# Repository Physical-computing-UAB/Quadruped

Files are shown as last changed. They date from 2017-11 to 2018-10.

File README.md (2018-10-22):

# Quadruped

Robot cuadrúpedo hecho con arduino y rasperry pi. Entre los dispositivos utilizados se encuentran:
- Motores Servo y paso a paso
- Sensores Ultrasonido HC-SRO4
- Camara raspberry NoIR
-
-

(Vídeos e imágenes: https://drive.google.com/drive/folders/1pMX80uz11Db60kt-JdsXifM1EmMQV496?usp=sharing)
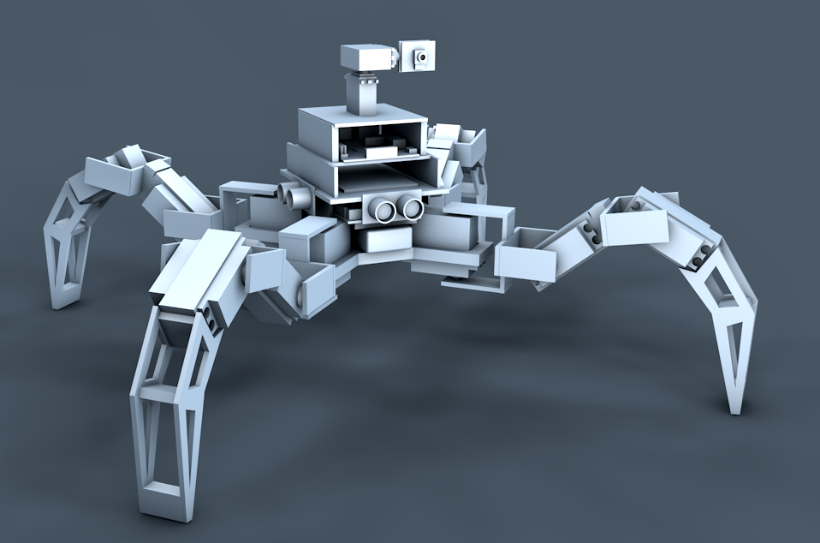
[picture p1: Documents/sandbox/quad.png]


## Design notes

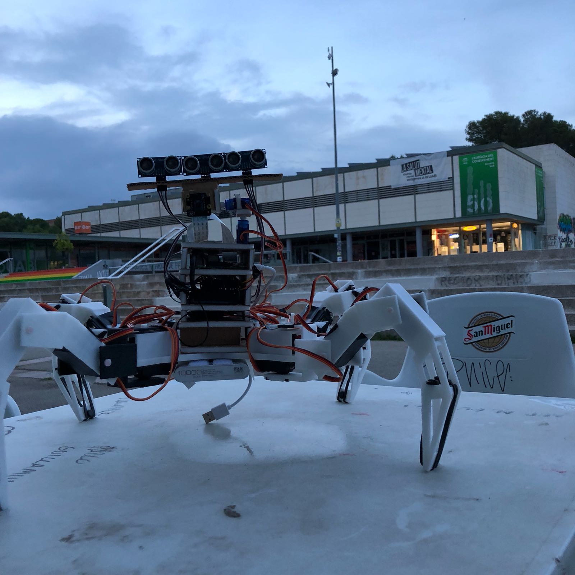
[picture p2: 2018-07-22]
Documents/pics/2018-07-21 at 21.26.33-2.jpeg

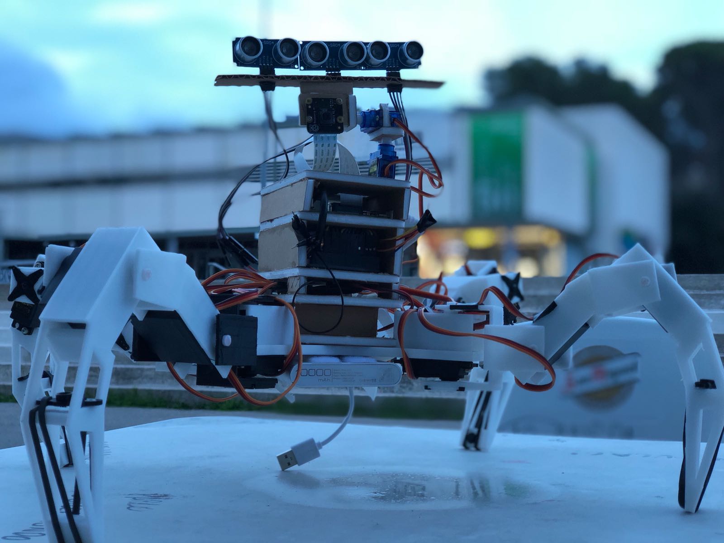
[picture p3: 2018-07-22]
Documents/pics/2018-07-21 at 21.26.32-2.jpeg

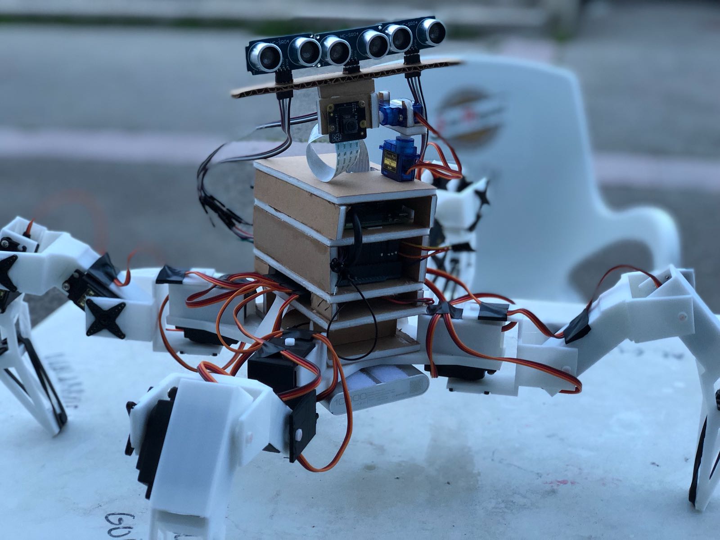
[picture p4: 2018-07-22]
Documents/pics/2018-07-21 at 21.26.33.jpeg

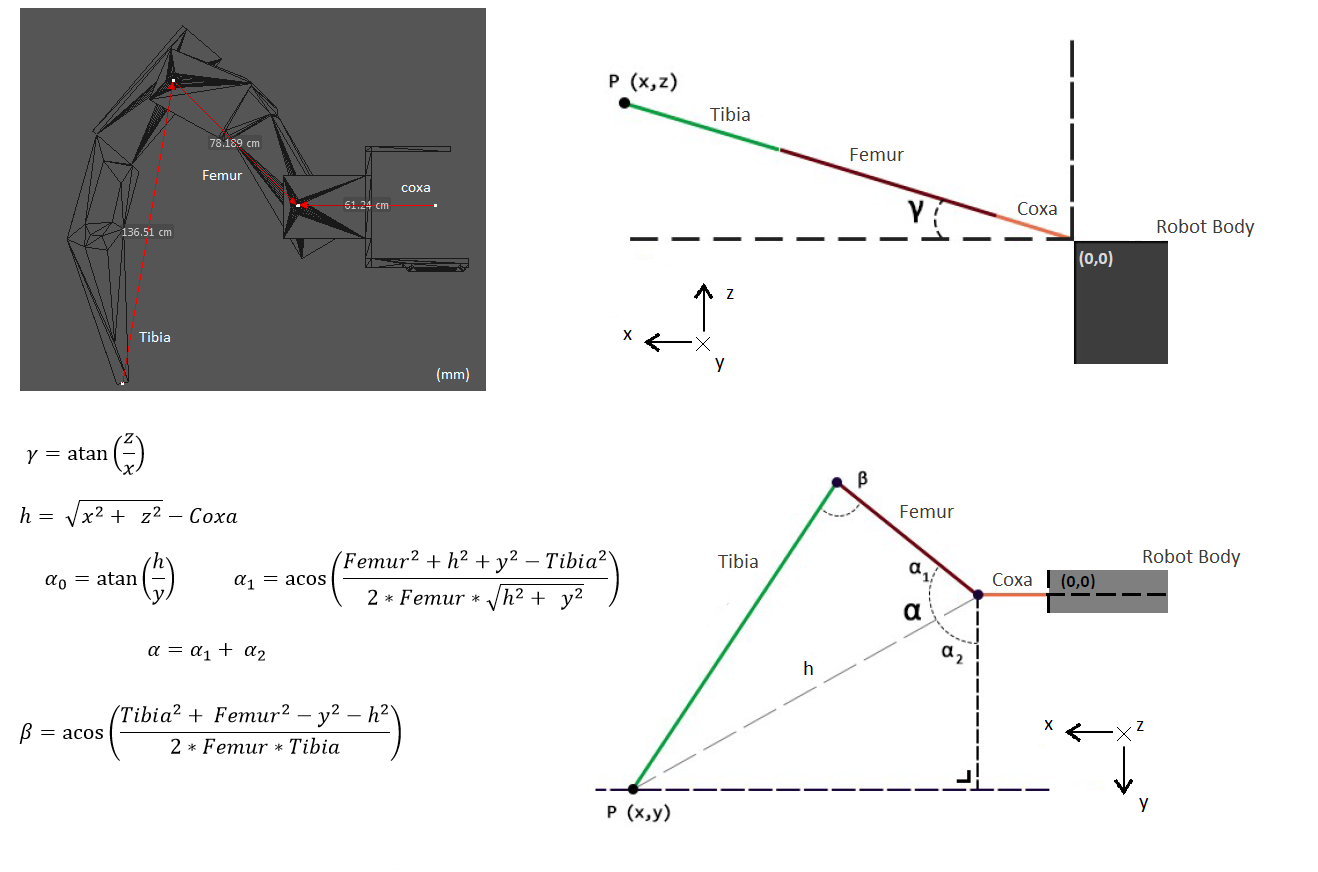
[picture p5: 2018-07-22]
Documents/pics/ik-diagram.png

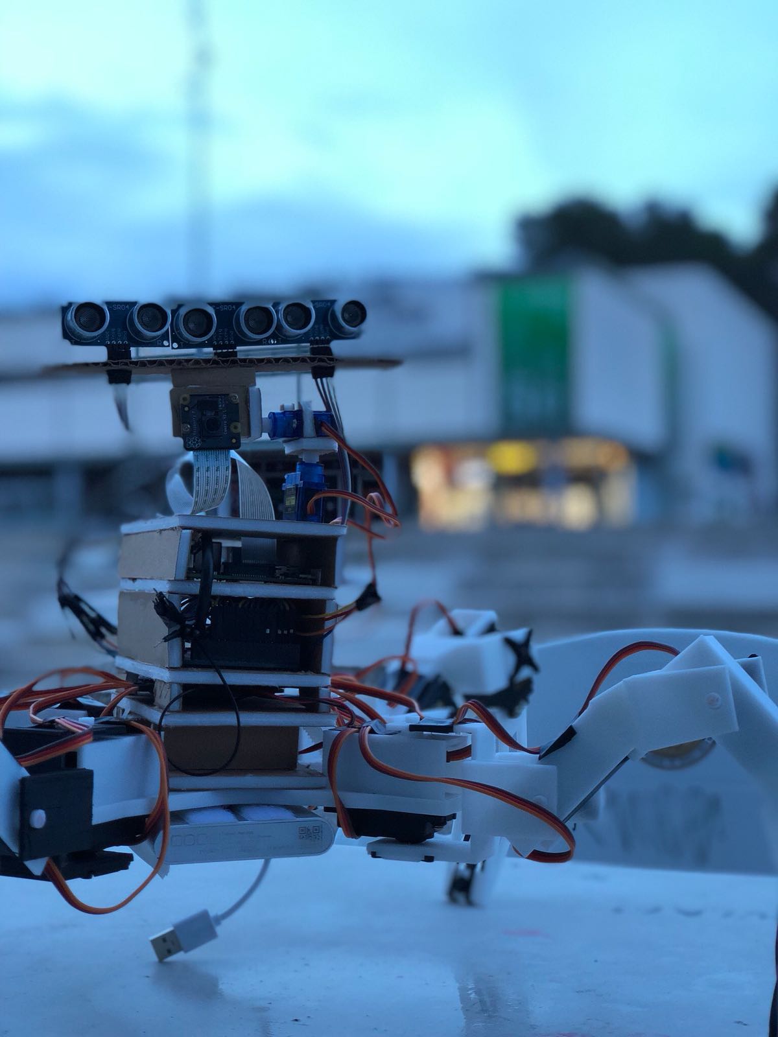
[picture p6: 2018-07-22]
Documents/pics/2018-07-21 at 21.26.32.jpeg

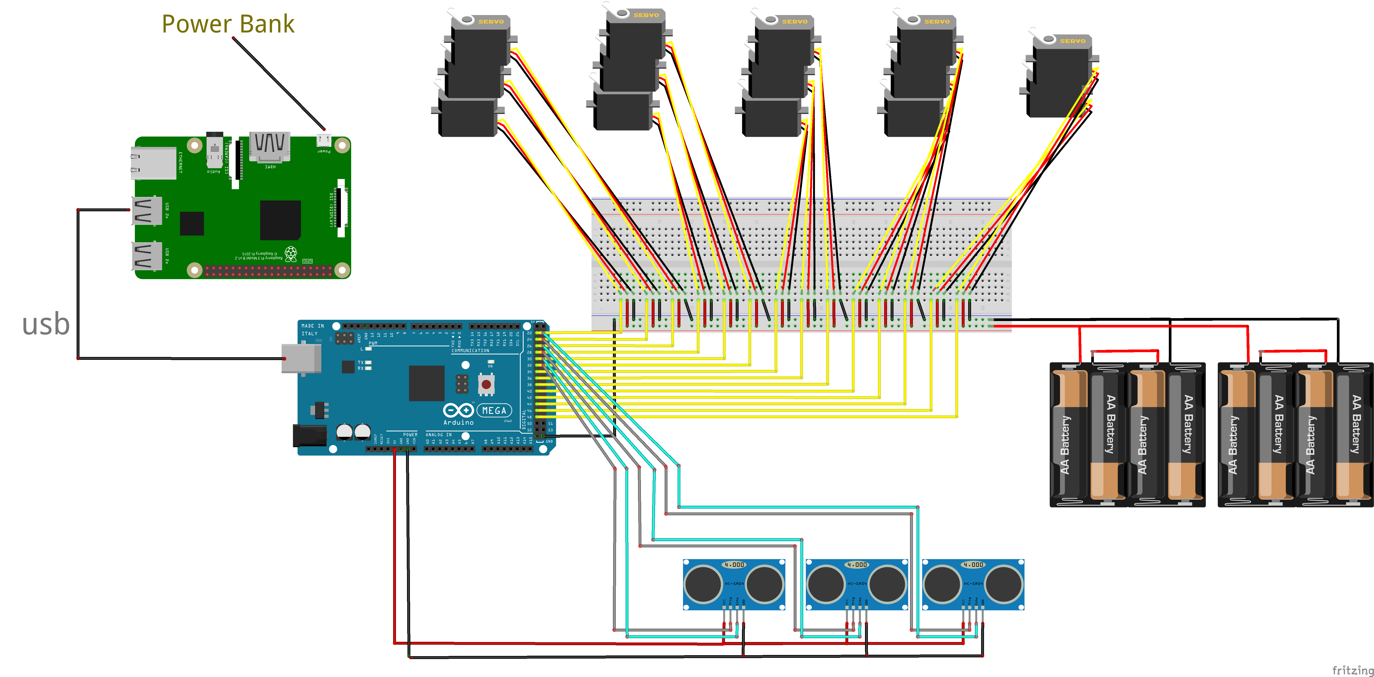
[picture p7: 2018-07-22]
Documents/fritzing_bb.png

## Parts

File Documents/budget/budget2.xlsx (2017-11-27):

Component | Preu € | Unitats | URL
Bateria Lipo 2200mah 2s 30c | 9.32 € | 1 | https://hobbyking.com/en_us/turnigy-2200mah-2s-30c-lipo-pack.html
Lipo cable jack | 1.30 € | 1 | https://hobbyking.com/en_us/xt60-male-to-2-dc-jack-plug-connectors-1pc.html
Cargador lipo | 4.14 € | 1 | https://hobbyking.com/en_us/turnigy-12v-2-3s-basic-balance-charger.html
Bec para raspberry |  | 1 | http://www.electan.com/bec-stepdown-voltage-regulator-p-5147.html | -> Sin Stock, alternativas: | 2.95 € | https://hobbyking.com/es_es/kingkong-5v-3a-ubec.html
 |  |  |  |  | o
 |  |  |  |  | 4.76 € | https://www.modmypi.com/raspberry-pi/power-1051/step-updown-and-regulators-1059/hobbywing-5v-3a-ubec-step-down-converter

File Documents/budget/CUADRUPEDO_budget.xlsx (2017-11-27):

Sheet: tienda.bricogeek.com
TOTAL DEL PROJECTE (automàtic) |  |  | 362.08
(Aferir-hi tots els components necessaris)
# | Component | Referncia | Preu € | Unitats | Total | URL
1 | Rasperry pi 3B | RSP-0031 | 39.95 | 1 | 39.95 | http://tienda.bricogeek.com/placas-raspberry-pi/811-raspberry-pi-3.html
2 | Servo mini sg90 | SRV-0016 | 4.9 | 2 | 9.8 | http://tienda.bricogeek.com/servomotores/968-micro-servo-miniatura-sg90.html
3 | HC-sr04 sensor de distancia | SEN-0054 | 3.3 | 3 | 9.9 | http://tienda.bricogeek.com/sensores-distancia/741-sensor-de-distancia-por-ultrasonidos-hc-sr04.html
4 | Samsung MicroSD | CPM-0081 | 18.2 | 1 | 18.2 | http://tienda.bricogeek.com/accesorios-raspberry-pi/789-memoria-microsd-32gb-clase-10-8806088676562.html
5 | Kit de cables para prototipado | PRO-0148 | 4.9 | 1 | 4.9 | http://tienda.bricogeek.com/cables/831-kit-140-cables-puente-para-prototipado.html
6 | Barra de contactos (Ángulo 90º) x 40 | CPM-0068 | 2.05 | 2 | 4.1 | http://tienda.bricogeek.com/componentes/642-barra-de-contactos-de-40-pines-angulo-90-grados.html
7 | Bobina cable | PRO-0002 | 2.8 | 1 | 2.8 | http://tienda.bricogeek.com/cables/876-bobina-de-cable-de-prototipo-negro.html
8 | Protoboard | PRO-0031 | 6.5 | 1 | 6.5 | http://tienda.bricogeek.com/herramientas-de-prototipado/239-placa-de-prototipo-16x5cm.html
9 | Goma antideslizante para patas | PRO-0073 | 1.2 | 1 | 1.2 | http://tienda.bricogeek.com/herramientas-de-prototipado/438-pies-de-goma-antideslizantes.html
10
 |  |  |  | Total | 97.35

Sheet: www.diotronic.com
TOTAL DEL PROJECTE (automàtic) |  |  | 362.08
(Aferir-hi tots els components necessaris)
# | Component | Referncia | Preu € | Unitats | Total | URL
1 | Arduino Mega | A000067 | 36 | 1 | 36 | http://www.diotronic.com/arduino-mega-atmel-atmega2560_26634/
2 | Placa soldar 70*90 | EF07080 | 3.03 | 2 | 6.06 | http://diotronic.com/placa-topos-70x90mm_28150/
3 | Placa soldar 50*70 | EF07078 | 1.57 | 2 | 3.14 | http://diotronic.com/placa-topos-50x70mm_28148/
4 | Servo | EF09011 | 14.52 | 13 | 188.76 | http://www.diotronic.com/servo-180%C2%A7-55g-torque-13kg-cm_27715/
5 | Cable USB arduino A/B | USB050/C | 1.79 | 1 | 1.79 | http://www.diotronic.com/93016-usb-a-b-acodado-0-5mts_31632/
6
7
8
 |  |  |  | Total | 235.75

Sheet: es.farnell.com
TOTAL DEL PROJECTE (automàtic) |  |  | 362.08
(Aferir-hi tots els components necessaris)
# | Component | Referncia | Preu € | Unitats | Total | URL
1 | Camara raspberry | 2510729 | 21.19 | 1 | 21.19 | http://es.farnell.com/raspberry-pi/rpi-noir-camera-board/raspberry-pi-noir-camera-board/dp/2510729
2 | Head pin x 40 | 1098454 | 2.24 | 1 | 2.24 | http://es.farnell.com/amp-te-connectivity/4-103321-8/conector-macho-pcb-2-54-mm-40/dp/1098454
3
4
5
6
7
8
 |  |  |  | Total | 23.43

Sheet: www.electan.com
TOTAL DEL PROJECTE (automàtic) |  |  | 362.08
(Aferir-hi tots els components necessaris)
# | Component | Referncia | Preu € | Unitats | Total | URL
1 | Jumper M/H 15cm x 20 | SPRKC-PRT-12794 | 1.85 | 2 | 3.7 | http://www.electan.com/jumper-wires-connected-pack-p-5974.html
2 | Jumper H/H 15cm x 20 | SPRKC-PRT-12796 | 1.85 | 1 | 1.85 | http://www.electan.com/jumper-wires-connected-pack-p-5973.html
3
4
5
6
7
8
 |  |  |  | Total | 5.55

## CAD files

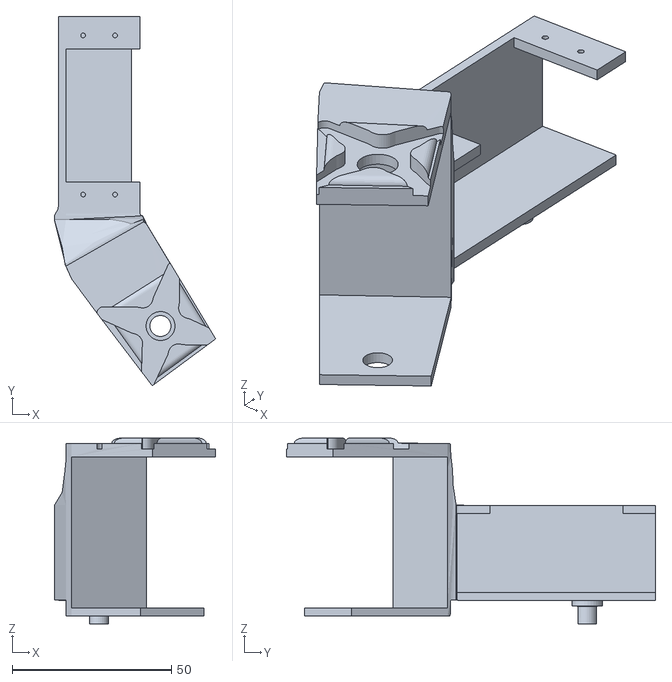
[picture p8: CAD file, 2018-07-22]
Documents/3D parts/femur-simetric.stl
50.7 x 116.1 x 58.4

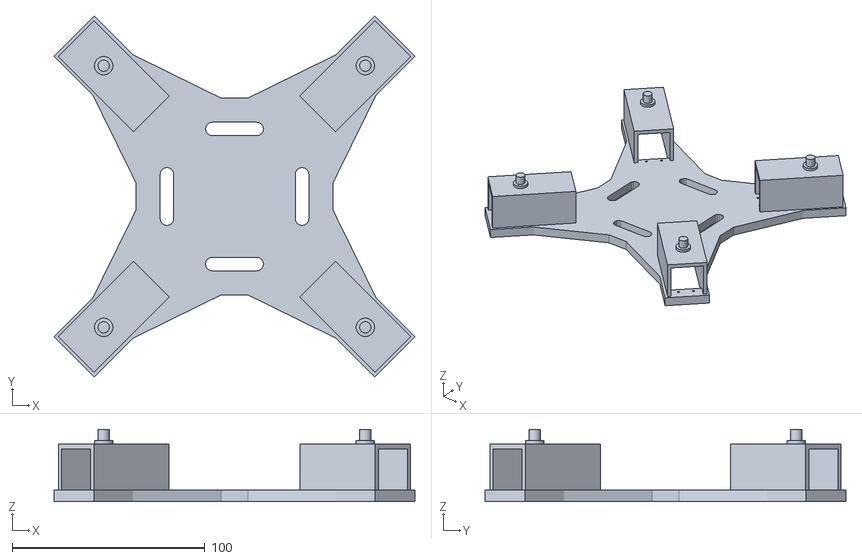
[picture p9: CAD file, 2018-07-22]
Documents/3D parts/base.stl
187.1 x 187.1 x 37.5

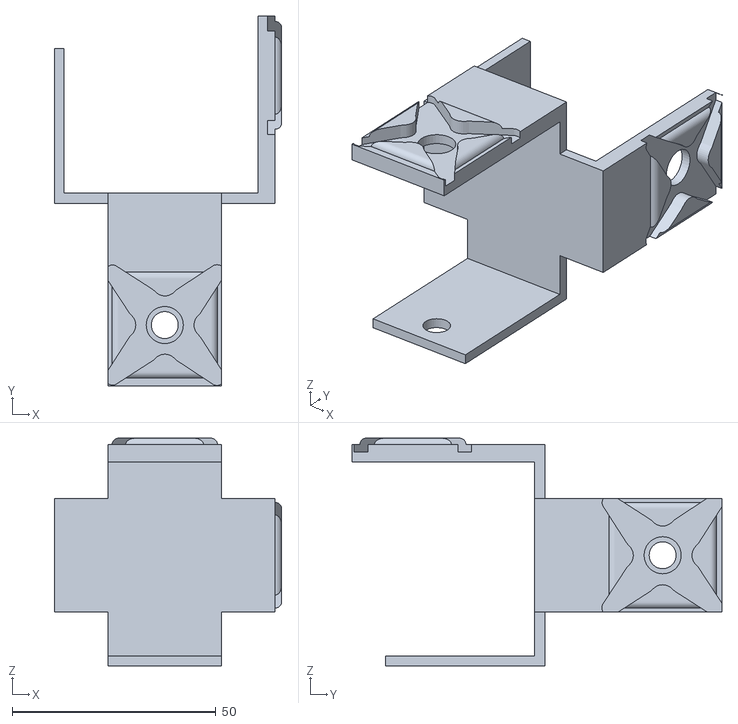
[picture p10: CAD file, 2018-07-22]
Documents/3D parts/coxa-Simetric.stl
55.7 x 90.7 x 55.8

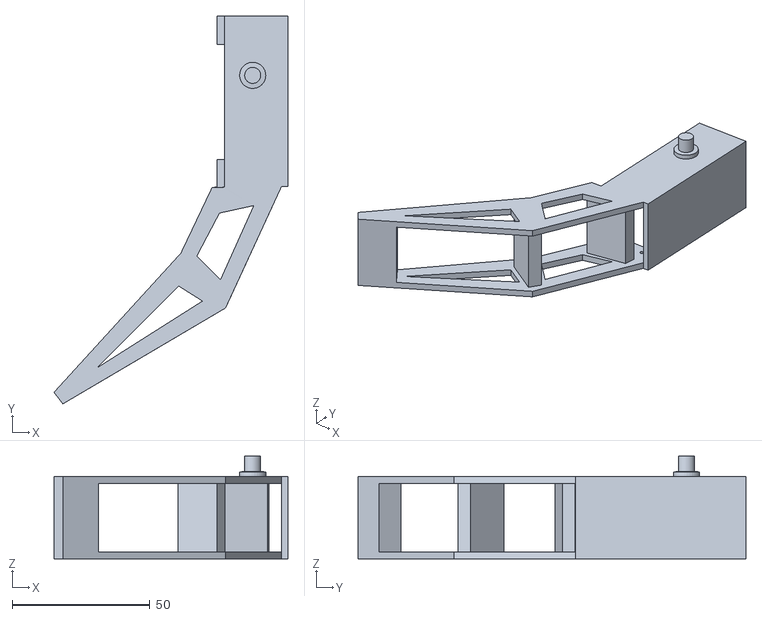
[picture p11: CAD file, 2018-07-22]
Documents/3D parts/tibia-Simetric.stl
84.8 x 140.5 x 37.2

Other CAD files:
Documents/3D parts/femur.stl
Documents/3D parts/coxa.stl
Documents/3D parts/tibia.stl

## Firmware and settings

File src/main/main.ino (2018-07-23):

#include <ArduinoSTL.h>
#include <CRobot.h>

const int DELAY_TIME = 200; // Time to think 

// Create instance of the robot.
CRobot* Robot = CRobot::Instance();

void setup() {
  Serial.begin(115200);
  Serial.println("setup(...)");
  
  // 1.- Initialize the peripherials of the robot.
  Serial.println("Initialiting robot.");
  Robot->init();
  Serial.println("+Done init...");
}

void loop() // The robot will be always running once it has been initialized
{
  
  // 2.- Handle the events of the robot.
  Robot->handleEvents();

  // 3.- Update the values of the peripherials and moving of the parts.
  Robot->update();

  // 4.- Move parts.
  
  Robot->run();
  
  delay(DELAY_TIME); // Time for the robot to think
}

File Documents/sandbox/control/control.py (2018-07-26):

from Tkinter import *
from ScrolledText import *
import time
import threading
import sys
import socket
#import serial
from functools import partial


class W1:
	
	def __init__(self, ip='192.168.4.1', port=8787):
	
		self.sender = Sender(ip, port)
		self.connected =  False
		
		self.root = Tk()
		self.root.geometry("1000x500")
		
		self.root.title("Quadruped Controller")
		

		# -------------------------------------------------------------------------	
		
		self.buttons = {}
		self.labels = {}
		self.scales = {}
		self.spinboxs = {}
		self.text = {}
		self.checkbuttons = {}
		
		self.toSend = set()
		
		# -------------------------------------------------------------------------	
		
		self.autoMode = False

		self.speedMax = 10
		self.speedMin = 1
		
		self.stepsMax = 10
		self.stepsMin = 1
		
		self.speed = IntVar()
		self.speed.set(8)
		
		self.anticolision = IntVar()
		self.anticolision.set(0)
		
		self.steps = IntVar()
		self.steps.set(1)

		self.dir = 0
		self.rot = 0
		
		self.camV = IntVar()
		self.camV.set(90)
		self.camH = IntVar()
		self.camH.set(90)
		
		
		self.wTo0 = False
		self.rTo0 = False
		
		# -------------------------------------------------------------------------	
		
		self.initElements()
		
		# -------------------------------------------------------------------------	
		
		self.activeKeys = set()
		self.root.bind_all('<KeyPress>', self.keyPressHandler)
		self.root.bind_all('<KeyRelease>', self.keyReleaseHandler)
		
		# -------------------------------------------------------------------------	
		
		self.speed.trace("w", self.update_sp)
		self.steps.trace("w", self.update_st)
		self.camV.trace("w", self.update_cam)
		self.camH.trace("w", self.update_cam)
		self.anticolision.trace("w", self.update_ac)

		self.root.after(1000, self.handleKeyActions)
		self.root.after(1000, self.send)
		self.root.after(1500, self.checkConn())
		self.root.focus_set()
		self.root.mainloop()



	def initElements(self):

		# ------ Frames ------
	
		movframe = LabelFrame(self.root, text="Movement")
		movframe.place(x=10,y=0)
		c = Label(movframe, text=" ")
		c.pack(padx=300,pady=110)
		
		camframe = LabelFrame(self.root, text="Camera control")
		camframe.place(x=600,y=0)
		c = Label(camframe, text=" ")
		c.pack(padx=190,pady=110)
	
		# ------ Scales ------

		# Speed
		sc_sp = Scale(self.root, variable=self.speed, from_=self.speedMin, to=self.speedMax, repeatdelay=1, showvalue=0, orient=HORIZONTAL)
		sc_sp.place(x=70, y=190)
		self.scales['sc_sp'] = sc_sp
		
		# Steps
		sc_st = Scale(self.root, variable=self.steps, from_=self.stepsMin, to=self.stepsMax, repeatdelay=1, showvalue=0, orient=HORIZONTAL)
		sc_st.place(x=70, y=220)
		self.scales['sc_st'] = sc_st
		
		
		# Cam V
		sc_cv = Scale(self.root, variable=self.camV, from_=0, to=180, repeatdelay=1, showvalue=0, orient=VERTICAL)
		sc_cv.place(x=680, y=70)
		self.scales['sc_cv'] = sc_cv
		
		# Cam H
		sc_ch = Scale(self.root, variable=self.camH, from_=0, to=180, repeatdelay=1, showvalue=0, orient=HORIZONTAL)
		sc_ch.place(x=800, y=190)
		self.scales['sc_ch'] = sc_ch
		

		# ------ Spin Box ------

		# Speed
		sp_sp = Spinbox(self.root, from_=self.speedMin, to=self.speedMax, repeatdelay=1, width=10, textvariable=self.speed)
		sp_sp.place(x=190, y=190)
		self.spinboxs['sp_sp'] = sp_sp
		
		# Steps
		sp_st = Spinbox(self.root, from_=self.stepsMin, to=self.stepsMax, repeatdelay=1, width=10, textvariable=self.steps)
		sp_st.place(x=190, y=220)
		self.spinboxs['sp_st'] = sp_st
		
		# Cam V
		sp_cv = Spinbox(self.root, from_=0, to=180, repeatdelay=1, width=10, textvariable=self.camV)
		sp_cv.place(x=650, y=190)
		self.spinboxs['sp_cv'] = sp_cv
		
		# Cam h
		sp_ch = Spinbox(self.root, from_=0, to=180, repeatdelay=1, width=10, textvariable=self.camH)
		sp_ch.place(x=910, y=190)
		self.spinboxs['sp_ch'] = sp_ch
		

		# ------ Labels ------
		
		# Movement
		ff = Label(self.root, text="forward (w)")
		ff.place(x=193,y=20)
		
		bw = Label(self.root, text="backward (s)")
		bw.place(x=193,y=135)
		
		r = Label(self.root, text="right (d)")
		r.place(x=325,y=102)
		
		l = Label(self.root, text="left (a)")
		l.place(x=82,y=102)

		rr = Label(self.root, text="rotate right (e)")
		rr.place(x=325,y=30)
		
		rl = Label(self.root, text="rotate right (q)")
		rl.place(x=46,y=30)
		
		sp = Label(self.root, text="Speed:", fg="black")
		sp.place(x=20,y=190)
		
		s = Label(self.root, text="Steps:", fg="black")
		s.place(x=20,y=220)
		
		# Camera
		tilt = Label(self.root, text="Tilt", fg="black")
		tilt.place(x=700,y=30)
		
		pan = Label(self.root, text="Pan", fg="black")
		pan.place(x=850,y=30)
		
		up = Label(self.root, text="    Up Key ^", fg="grey47")
		up.place(x=610,y=70)
		
		dw = Label(self.root, text="Down Key v", fg="grey47")
		dw.place(x=610,y=155)
		
		lb_x = Label(self.root, text="< Right Key", fg="grey47")
		lb_x.place(x=750,y=220)
		
		lb_y = Label(self.root, text="Left Key >", fg="grey47")
		lb_y.place(x=889,y=220)
		
		
		# ------ Buttons ------
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

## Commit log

2017-11-19 actualizado en budget
    [presupuesto.xlsx, presupuestoFinal.xlsx]
2017-11-27 Presupuesto final
    [CUADRUPEDO_budget.xlsx]
2017-11-27 Presupuesto viejo
    [presupuesto.xlsx]
2017-11-27 Presupuesto con webs distintas
    [budget2.xlsx]
2017-12-04 Controla por USB el angulo de un servo conectado a Arduino, a traves del teclado
2017-12-04 Control de servo en arduino por serial usb
2017-12-04 GUI para controlar un servo por UDP. (Varios bugs con Windows por la gestion de los threads)
2017-12-04 Test de una GUI en python
2017-12-04 Controla un servo a partir de la entrada por usb
2017-12-04 GUI para controlar un servo por UDP. (Bugs en Windows a causa de la gestion de los threads)
2017-12-04 Escribe por un puerto serial la entrada por teclado
2018-01-31 GUI para controlar los servos de la camara
2018-01-31 Control de los 2 servos de la camara a traves de usb
2018-02-07 Poner la camara de la raspberry en streaming
2018-02-07 Escucha por un purto udp y envia el mensaje por usb
2018-02-12 Latencia de la camara reduciada a ~100ms
2018-02-17 Add files via upload
    Primer borrador de 3 sensores en funcionamiento y un intento de librería para manejar un array de sensores.
2018-02-17 Sensores Ultrasonido
    Prueba y primera implementación de una librería para manejar varios sensores.
2018-02-18 codigo base para procesar comandos enviados a arduino por usb
2018-02-20 Programa principal de Arduino
2018-02-21 añadido codigo para debug
2018-02-23 1era version funcional de la libreria UltrasonicLib
    "Ultrasonic.ino" contiene el uso de los sensores detalladamente.
    "UltrasonicLib.ino" utiliza la librería UltrasonicLib implementada por mi. Se agradece la corrección de errores.
    La librería esta implementada en C++. Consta de un struct "UltrasonicSensor" que representa un (1) sensor y una clase "UltrasonicSensorArray" que permite gestionar n sensores con menos código.
2018-03-07 nuevas medidas de coxa, femur y tibia
2018-03-07 Mover una pata en los ejes x e y por medio de dos potenciometros para provar la IK
2018-03-07 Establecer los angulos de dos servos de una pata a traves de dos potenciometros
2018-04-15 Primer disenyo de MSF
2018-05-01 Testeando funcionalidad de FSM
2018-05-01 Diagrama de clases
2018-05-18 Cambios importantes, anyadido un test funcional a scr/. Compila y cambia de estados sin problema.
    [CUADRUPEDO_budget.xlsx, budget2.xlsx]
2018-05-18 Reorganizar el repositorio
    [CUADRUPEDO_budget.xlsx, budget2.xlsx]
2018-07-03 python gui to move legs
2018-07-12 Raspberry server
2018-07-22 tibia part
    [tibia.stl]
2018-07-22 tibia simetric part
    [tibia-Simetric.stl]
2018-07-22 all parts added
    [fritzing.fzz]
2018-07-22 femur part
    [femur.stl]
2018-07-22 coxa part
    [coxa.stl]
2018-07-22 coxa simetric part
    [coxa-Simetric.stl]
2018-07-22 base part
    [base.stl]
2018-07-22 scale fix
    [femur.stl]
2018-07-22 femur simetric part
    [femur-simetric.stl]
2018-07-22 diagram of inverse kinematics
2018-07-23 Primera version funcional de ambos codigos juntos
2018-07-23 reducido el delay time
2018-07-23 modificada la matriz de andar
2018-07-23 bug en la funcion movlegs corregido
2018-07-23 modificados y añadidos mas headers en la comunicacion serial
2018-07-25 añadido control de la velocidad y pasos
2018-07-26 Deteccio'n de objetos
2018-07-26 comentados los prints
2018-07-26 no walk bug fix
    [QServer.py]
2018-07-26 modificado el tiempo de delay
2018-07-26 Descomentado attach de los servos
2018-10-22 Update README.md
    Añadido link de vídeos e imágenes
